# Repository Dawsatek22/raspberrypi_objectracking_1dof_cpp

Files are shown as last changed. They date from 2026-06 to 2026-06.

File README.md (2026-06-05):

# raspberrypi_objectracking_1dof_cpp
A raspberry pi 1dof object tracking robot using c++,raspberry pi camera module/us camera.Tutorials,stl parts coming later.For now recommended software: lccv( [https://github.com/kbarni/LCCV](https://github.com/kbarni/LCCV.git) ),raspberry pi os,PiPCA9685( https://github.com/barulicm/PiPCA9685.git),And the project was used through ssh using vnc viewer.More update coming up.

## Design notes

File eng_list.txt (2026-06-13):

? playlist tutorial video:
00:00 Playlist:
00:05:Warnings.
00:09:start to assemble the robot.
11:48:ssh into the pi and test the code.
12:56:showing the finished robot.
13:24:outro.

?:Warning and summaries:
This is a english list for the Raspberry pi 1 degrees of freedom tracking robot,Links for  tools and materials are more for reference than a nessecary link,You can find the required tools else if you want,The tutorial is explained in text so take that in mind,The tutorial is with the raspberry pi camera module in mind but there is also code for a usb camera option in the repo.But there is no specific usb camera holder stl file currently,
If there is something wrong please reply if possible.

Required software:

opencv c++ version for the Raspberry Pi ( https://opencv.org/get-started/?utm_source=opcv&utm_medium=home ),lccv for Raspberry Pi camera ( https://github.com/kbarni/LCCV.git ),
PIPCA9685 software for the Raspberry Pi ( https://github.com/barulicm/PiPCA9685.git ),
vnc viewer for pc/laptop ( https://www.realvnc.com/en/connect/download/viewer/?lai_sr=0-4&lai_sl=l&lai_p=1&lai_na=488119 ),
vscode or other editor for c++ and cmake and Raspberry Pi (optional).
Recomended skills:
c/c++ programming,ssh into a Raspberry Pi with vnc viewer,
using opencv in c++,Aquiring 3d printed parts or making parts,
screwing parts together.Working with 5V power supplies.

Tools and hardware:

1x pc/laptop
1x wifi access
1x micro sd card with Raspberry Pi os installed(newest recommended).
1x MG9685R servo motor ( https://www.google.com/aclk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 ).
1x Raspberry Pi 4 power supply ( https://www.kiwi-electronics.com/nl/raspberry-pi-boards-behuizingen-uitbreidingen-en-accessoires-59/raspberry-pi-45w-usb-c-power-supply-wit-eu-20344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 ).
1x Raspberry Pi 4 4gb or more board ( https://www.kiwi-electronics.com/nl/raspberry-pi-boards-behuizingen-uitbreidingen-en-accessoires-59/raspberry-pi-4-model-b-4gb-4268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 ).
1x Raspberry Pi camera module 2 ( https://www.kiwi-electronics.com/nl/raspberry-pi-boards-behuizingen-uitbreidingen-en-accessoires-59/raspberry-pi-camera-accessoires-133/raspberry-pi-camera-module-2-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 ).
1x Raspberry Pi Camera and Display Cable - 15 pin FFC flex - 30cm (https://www.tinytronics.nl/en/cables-and-connectors/cables-and-adapters/ffc/raspberry-pi-camera-cable-15-pin-fpc-flex-30cm).
1x Servo Driver HAT for Raspberry Pi - 16ch - 12-bit - I2C or PCA9685 board as alernative  ( https://www.kiwi-electronics.com/en/servo-driver-hat-for-raspberry-pi-16ch-12-bit-i2c-10373?country=NL ).
3x 20mm m/f dupont wires ( https://www.amazon.nl/Dupont-Jumper-Arduino-Raspberry-projects/dp/B09KGRM98K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 )
1x yellow object for testing like a dc tt motor wheel for example( https://www.tinytronics.nl/en/mechanics-and-actuators/parts/wheels/spare-wheel-auto-kit-diy )
1x m2.5 allen wrench
1x m3 allen wrench
1x m4 allen wrench

Screws and nuts and spacers:
2x m2 nuts
6x m3 nuts
2x m4 nuts
2x m2.5x10+6mm Brass standoff spacers
2x m2x8mm allen screws.
4x m2.5x6mm allen screws
1x m3x6mm allen screws
2x m3x12mm allen screws
2x m3x16mm allen screws
2x m4x16mm allen screws

Cad parts to print(pla recomended):
1x mg995_bottom.stl
1x nikodembartnik-216-plate.stl
1x dt22-226-cam_2-forward.stl
1x Radek_Janecka-172-RaspberryPi_holder.stl
1x orp_extender60mm(mg996r_v).stl

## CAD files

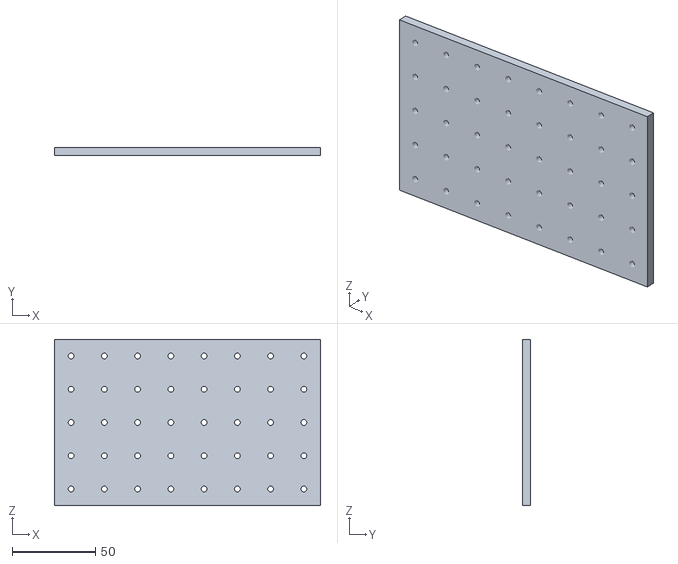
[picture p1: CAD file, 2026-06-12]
cad_files/nikodembartnik-216-plate.stl
160.0 x 5.00 x 100.0

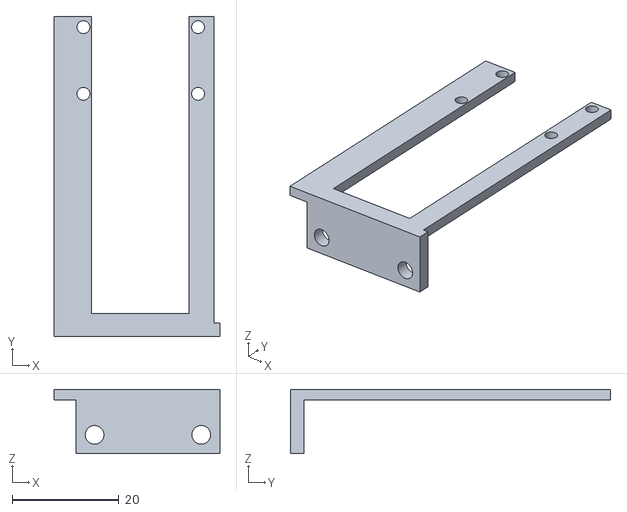
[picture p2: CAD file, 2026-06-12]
cad_files/dt22-226-cam_2-forward.stl
31.1 x 60.0 x 12.0

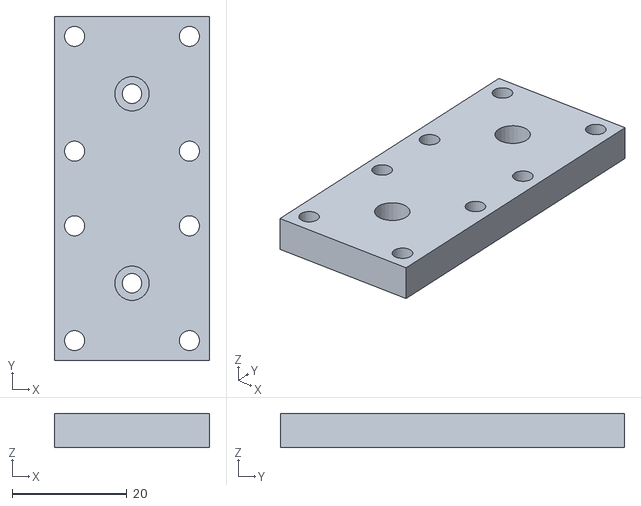
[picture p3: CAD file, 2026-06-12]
cad_files/orp_extender60mm(mg996r_v).stl
27.0 x 60.0 x 6.00

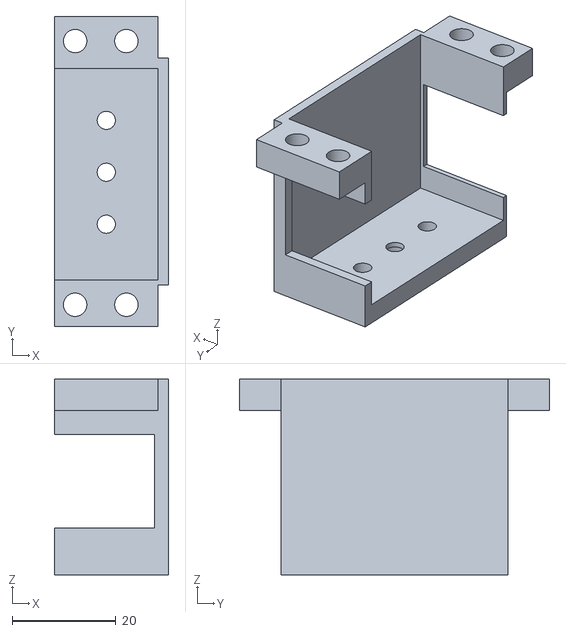
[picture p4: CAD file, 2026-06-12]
cad_files/mg995_bottom.stl
22.0 x 59.7 x 37.7

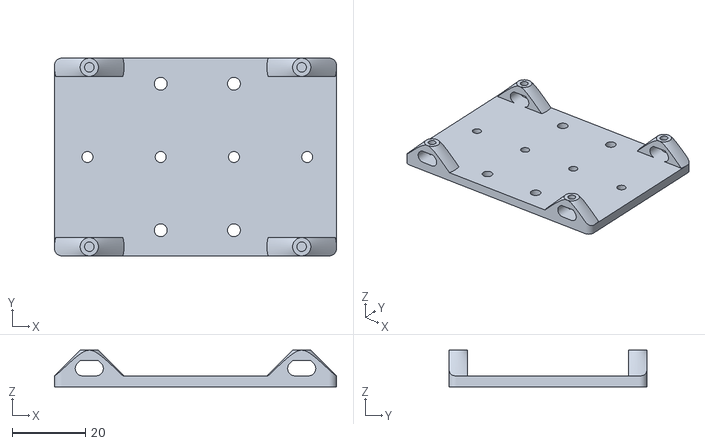
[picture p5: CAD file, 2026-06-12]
cad_files/Radek_Janecka-172-RaspberryPi_holder.stl
77.0 x 54.0 x 10.0

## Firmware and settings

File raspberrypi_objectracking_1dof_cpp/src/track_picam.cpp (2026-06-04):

// this is a code to track a color object with a usb camera and  a MG996R servo in the x direction angle 
#include <iostream> // for input and output stream
#include <opencv2/opencv.hpp> // to use opencv functions
#include <libcamera_app.hpp> // to use libcamera functions
#include <lccv.hpp> // to use lccv functions
#include <PiPCA9685/PCA9685.h> // pca9685 header

#define SERVOMIN 300// This is the minimum pulse length count (out of 4096)
#define SERVOMAX 575// This is tqhe maximum? pulse length count (out of 4096)
// the map function is created below to map the SERVOMIN and SERVOMAX values
long mapservo(long x, long in_min, long in_max, long out_min, long out_max) {
  return (x - in_min) * (out_max - out_min) / (in_max - in_min) + out_min;
}

int pulsval; // pulse value
int servoval; // map value for thr servos
int position; //  value for the servo
int center= 91 ; // is the value of the center x value that was calculated
int x_medium; //  x range value  thats gets measured

using namespace cv;

int main() {

PiPCA9685::PCA9685 track{"/dev/i2c-1",0x40}; // creates servo object.
// if PCA9685 default adress = 0x40 you can also do: PiPCA9685::PCA9685 track{}; instead. 
track.set_pwm_freq(60.0);
servoval = mapservo(pulsval,0,180,SERVOMIN,SERVOMAX);
track.set_pwm(0,90,servoval); //  servos is calibrated
std::cout << "servo is set to 90 degrees angle"<< '\n';
sleep(2);
 

uint32_t num_cams = LibcameraApp::GetNumberCameras();
std::cout << "Found " << num_cams << " cameras." << std::endl;
uint32_t width = 980; // the width of the camera
uint32_t height = 580; // height of the camera

Mat frame = Mat(height, width, CV_8UC3); // Mat object is made


// below are lccv camera configuration
lccv::PiCamera cam(0);
cam.options->brightness=0.5; // warning brightness can affect performance
cam.options->video_width=width;
cam.options->video_height=height;
cam.options->framerate=30;
cam.options->verbose=true;
cam.startVideo();





while (true) {
 

// yellow wraps around hue=0, so use two ranges.
Scalar lower_color1(22, 38, 160);
Scalar upper_color1(33, 244, 255);
Scalar lower_color2(23, 39, 170);
Scalar upper_color2(34, 244, 255);
Mat mask1 ,mask2, mask, hsv; // creates mat objects for mask and hsv
cvtColor(frame , hsv,COLOR_BGR2HSV);
inRange(hsv,lower_color1,upper_color1,mask1);
inRange(hsv,lower_color1,upper_color2,mask2);
mask = mask1 | mask2 ;

if (!cam.getVideoFrame(frame,1000)) {
std::cout << "frame not openend"<<'\n';
cam.stopVideo();
break;
}

// Clean noise before contour extraction.
Mat kernel = getStructuringElement(MORPH_ELLIPSE,Size(5,5)); // creates structuring element
erode(mask, mask, kernel); // erodes mask
dilate(mask, mask, kernel); // dillates mask

std::vector<std::vector<Point>> contours; /// creates coutours

findContours(mask, contours,RETR_EXTERNAL, CHAIN_APPROX_SIMPLE); // finds coutours
// below checks if the frame video frame is availabe



 for (std::size_t i = 0; i < contours.size(); ++i) {
        double const area = contourArea(contours[i]);
        if (area <= 500) {
            continue;
        }
           // creates object for detecting color
         Rect const box = boundingRect(contours[i]);
        x_medium = int(box.x + box.width/ 2   ); // is the x direction converted into a int
        //  puts a rectangle on countour
        rectangle(frame, box,Scalar(60, 255, 255), 2);
        std::cout << "color is " <<  area << '\n';
       // put the color name on the countour
       putText(
            frame,
            "yellow",
            box.tl(),
            cv::FONT_HERSHEY_SIMPLEX,
            1.0,
            cv::Scalar(255, 230, 70),
            2
        );
    }

 int error = x_medium/6; // supossed to be the offset
//position = error;

std::cout << "position of center" << center <<'\n';
std::cout << "position of error" << error <<'\n';

std::cout << "position of x_medium" << x_medium <<'\n';

if (error > center) {


    position += 4;
}



if (error < center) {


    position -= 4;
}

// position limits are set below
if (position < 1) {

position = 0;
std::cout << "position of servos is reached 0" << '\n';

}



if (position > 180 ) {

position = 180;
std::cout << "position of servos is reached 180" << '\n';

}


 track.set_pwm(0,position,servoval); // moves servos acording to the position value

imshow("hsv",hsv); // optional
imshow("mask",mask); // optional
 imshow("show_coutours",frame); // now shows frame

if (waitKey(1) == ('q')) { // breaks loop when pressed q
    cam.stopVideo();
    destroyAllWindows();
    break;

}}}

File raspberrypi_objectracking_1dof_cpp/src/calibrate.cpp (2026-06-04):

// this is a code to calibrate the servo
#include <unistd.h> // if you need the sleep function
#include <iostream> //for input and output
#include <PiPCA9685/PCA9685.h> // pca9685 header

#define SERVOMIN 300// This is the minimum pulse length count (out of 4096)
#define SERVOMAX 575// This is the maximum? pulse length count (out of 4096)
// the map function is created below to map the SERVOMIN and SERVOMAX values
long map(long x, long in_min, long in_max, long out_min, long out_max) {
  return (x - in_min) * (out_max - out_min) / (in_max - in_min) + out_min;
}
int pulsval; // pulse value
int servoval;

int main() {

  PiPCA9685::PCA9685 pca{"/dev/i2c-1",0x40};
 pca.set_pwm_freq(60.0); // current frequency used
int servoval = map(pulsval,0,180,SERVOMIN,SERVOMAX);

   

    pca.set_pwm(0,90,servoval);
   


std::cout << "servo is calibrated to prefered position" << '\n';



}
